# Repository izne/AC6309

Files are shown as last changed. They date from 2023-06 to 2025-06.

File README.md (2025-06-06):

# AC6309 Platform
A minimalistic industrial computer core, based on Motorola 6809 architecture.

## Purpose
Proof of concept custom 8-bit industrial computer with minimal device count implementation. Modular, low-power design, allowing easy expansion and customization per use case.

## Dedication
AC29 is dedicated to my beloved father.

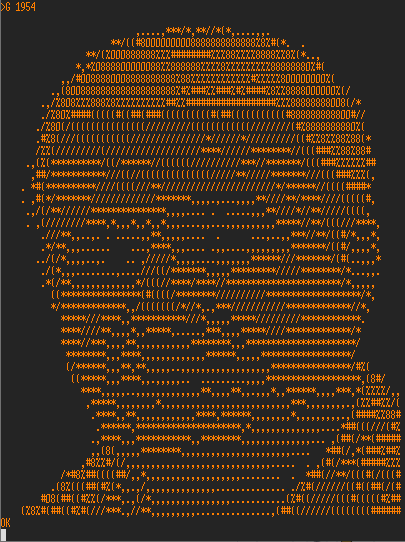
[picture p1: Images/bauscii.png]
BAUS


## AC29 projected configuration
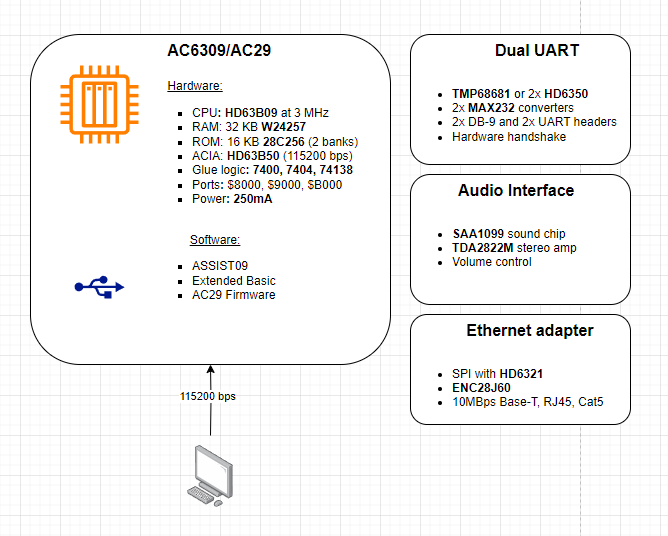
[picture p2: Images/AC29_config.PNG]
AC29 Config


## Prototype build 
* CPU: HD63B09 @ 1.8432MHz
* RAM: 32KB W24257A
* ROM: 8KB 28C256 (2x ROMs)
* UART: HD63B50 (1MBps) on FT23 USB Serial
* Address decoding: 74HCT00 & 74HCT138
* Expansion: 1x 40-pin header for expansion board with 3 slots mapped at $8000, $9000 and $B000
* Power over USB

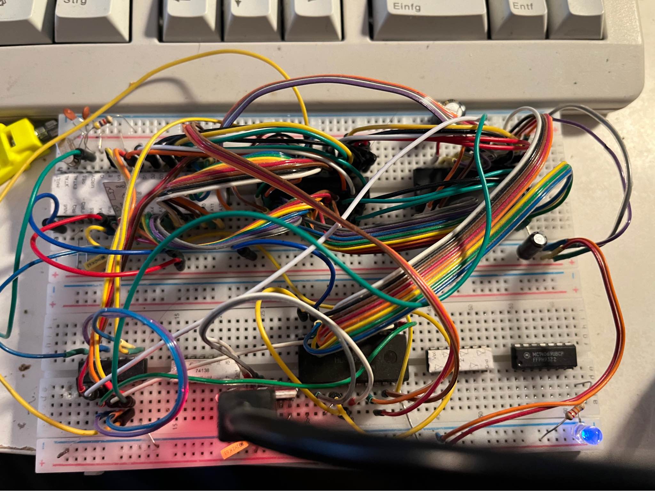
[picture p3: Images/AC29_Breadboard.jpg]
AC29 Breadboard


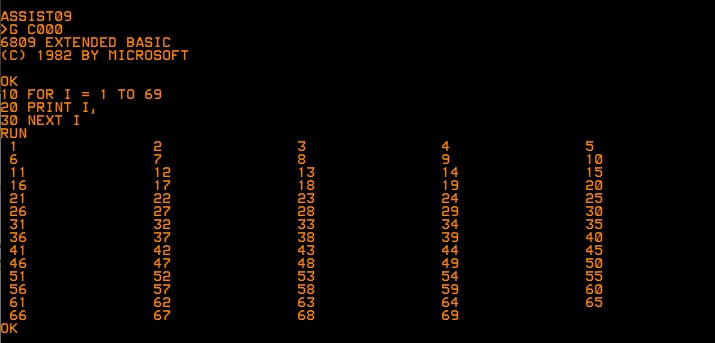
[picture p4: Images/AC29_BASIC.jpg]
AC29 BASIC


## Example physical layout
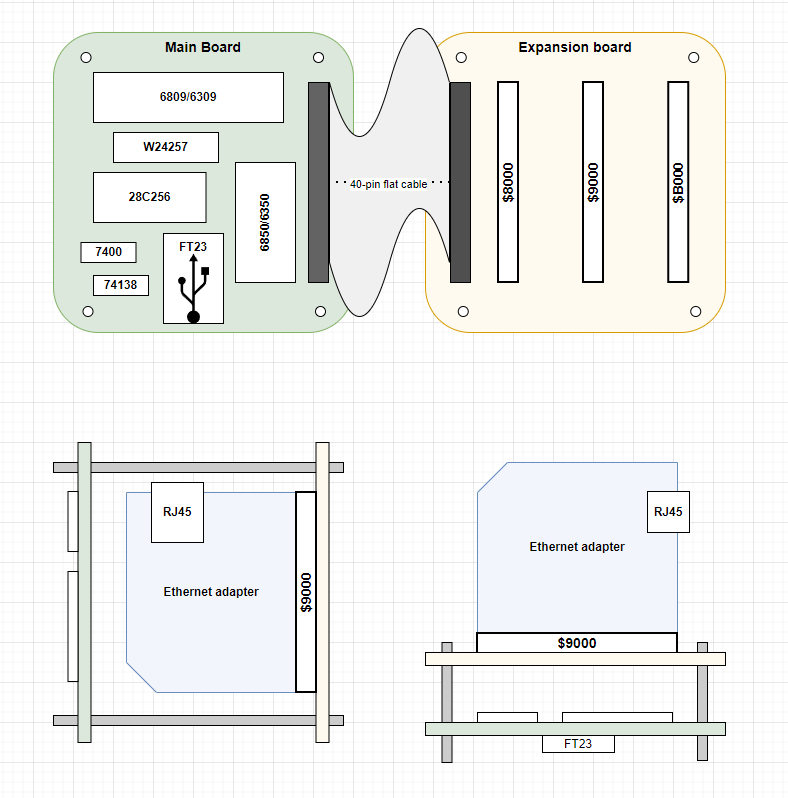
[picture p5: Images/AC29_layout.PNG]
AC29 Layout


## PCB Updates
Current state of PCB design:
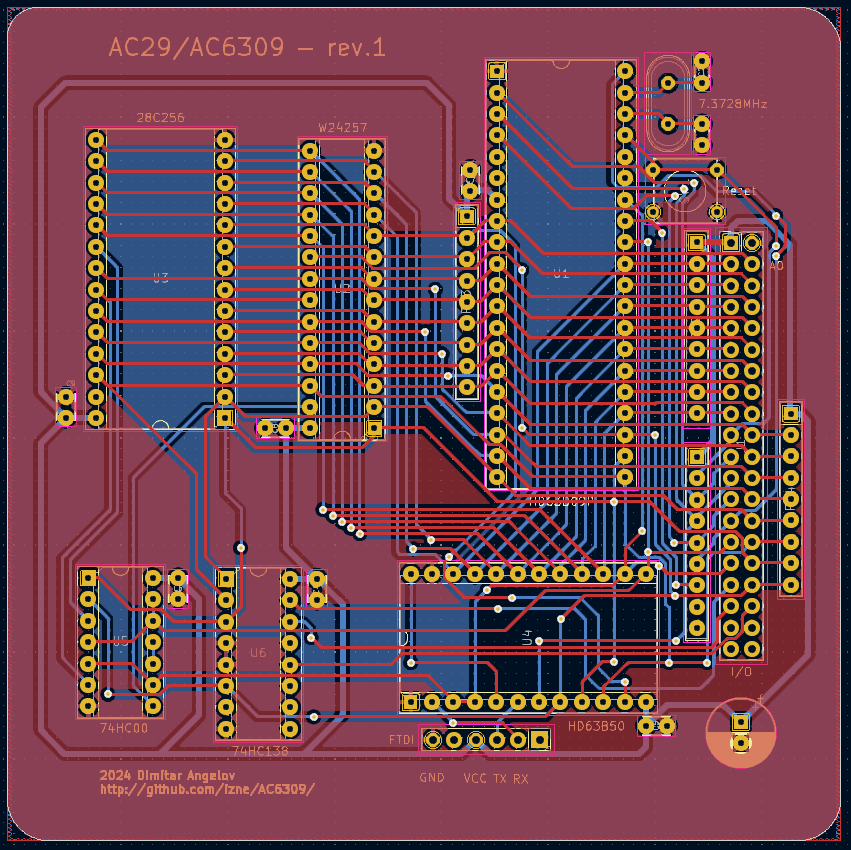
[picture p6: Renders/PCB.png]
AC29 PCB

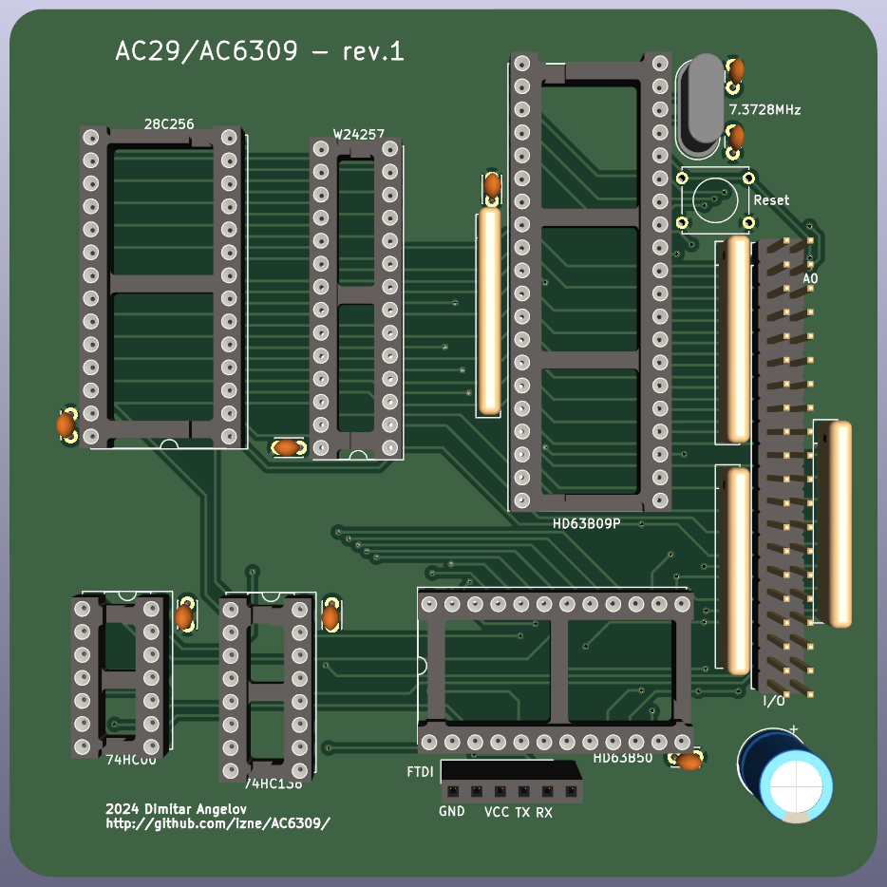
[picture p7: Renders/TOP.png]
AC29 TOP

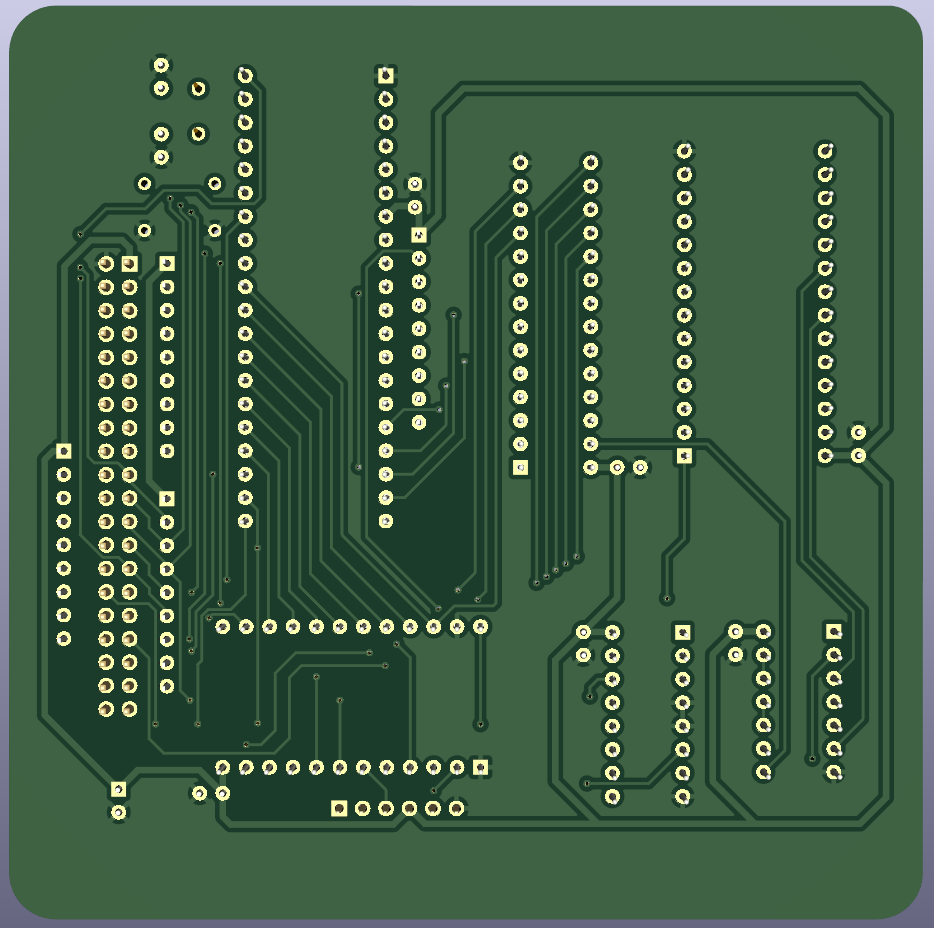
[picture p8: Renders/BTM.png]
AC29 BTM


## System memory map
|Address range|Device|Size|
|---|---|----|
|$0000-$7FFF|RAM|32KB|
|$8000-$8FFF|Extension port #1|4KB|
|$9000-$9FFF|Extension port #2|4KB|
|$A000-$AFFF|UART|4KB|
|$B000-$BFFF|Extension port #3|4KB|
|$C000-$FFFF|ROM|16KB|

The 32KB of RAM is allocated from the bottom of the address range $0000 to $7FFF.
The ROM is allocated at top 8KB of the address space starting $C000 to $DFFF.

The I/O mapping is allowing compatibility with existing BIOS images having ACIA on address 0xA000. 

## Writing the ROM image
Using the combination ROM image in Intel HEX format it needs first be turned into a binary image to be written to the EEPROM.
> objcopy -I ihex -O binary combined.hex combined.bin

Write the resulting .bin file using the specially created EEPROM programmer for AT28C-series EEPROMs. Or any other.
> promdude.exe -f combined.bin

As a note, burning the combined.bin (16K) onto 32K 28C256 has to be at the correct half. Optionally, a copy of combined.bin twice into the chip will do as well.

## ROM switching
As the firmware is 16K and 28C256 (32K) chips are nowadays more accesible, two firmware images could be stored in the full 32K capacity of the chip. A ROM switching key to be implemented on the board, to switch the higher or lower part of the chip to be "visible" (A14) at boot.

## Communication
The system communicates with a terminal via USB serial connection using the included ACIA device and its UART capability, coupled with an FTDI232 header. Terminal serial port settings: 115200 baud, 8n1, no hardware handshake yet.

## Software checklist
- [x] Run ASSIST09 and Extended BASIC
- [x] Write basic program (asm)
- [x] Cross-compile on host machine
- [x] Easy program transer via ASSIST09 Load (S19)
- [ ] Use of high level C code (CMOC)

## Hardware checklist
- [x] Breadboard prototype running
- [x] Revision 1 completion and PCB fabrication
- [ ] Extended addressing ("A" - four internal devices, "B" - four external devices)
- [ ] Expansion board with easy coupling
- [ ] 28C16-based address decoder
- [ ] Expansion card: Am9511 card (Am9511, 3MHz osc, 5to12Vbuck)
- [ ] Expansion card: Tape interface
- [ ] Expansion card: TMP68681 / 2x RS232 / 115200 bps (own osc)
- [ ] Expansion card: Ethernet adapter (ENC28J60)
- [ ] Expansion card: SAA1099 + TDA2822 audio interface
- [ ] Expansion card: VGA and PS/2 (Arduino)
- [ ] Expansion card: VGA and PS/2 (MC6845/HD6321)
- [ ] Expansion card: VGA (EF9367)
- [ ] Expansion card: Keyboard controller (XT, AT, PS/2, USB)

## Toolchain
* [ASM6809](https://www.6809.org.uk/asm6809/doc/asm6809.shtml)
* [A09](https://github.com/Arakula/A09)
* [AS09](https://gitlab.com/dfffffff/as09)
* [LWTOOLS-4.20](http://www.lwtools.ca/)
* [CMOC](http://perso.b2b2c.ca/~sarrazip/dev/cmoc.html)
* [MillFork](https://github.com/KarolS/millfork)

## Emulators
* [6809 online assembler](http://6809.uk/)
* [XRoar](https://www.6809.org.uk/xroar/online/)

- - - 
#### Prerequisites
The schematics and PCB design is made with [KiCad](http://kicad.org)

#### References and inspiration:
* [sbc689 by Jeff Tranter](https://github.com/jefftranter/6809)
* [6809 computer by Grant Searle](http://searle.x10host.com/6809/Simple6809.html)
* [HB6809 by Lindoran](https://github.com/lindoran/HB6809)
* [OMEN Kilo](https://github.com/omenmicro/kilo)
* [Chip Labels by Grant Searle](http://searle.x10host.com/labels/ChipLabels.pdf)

### Some great oldschool books:

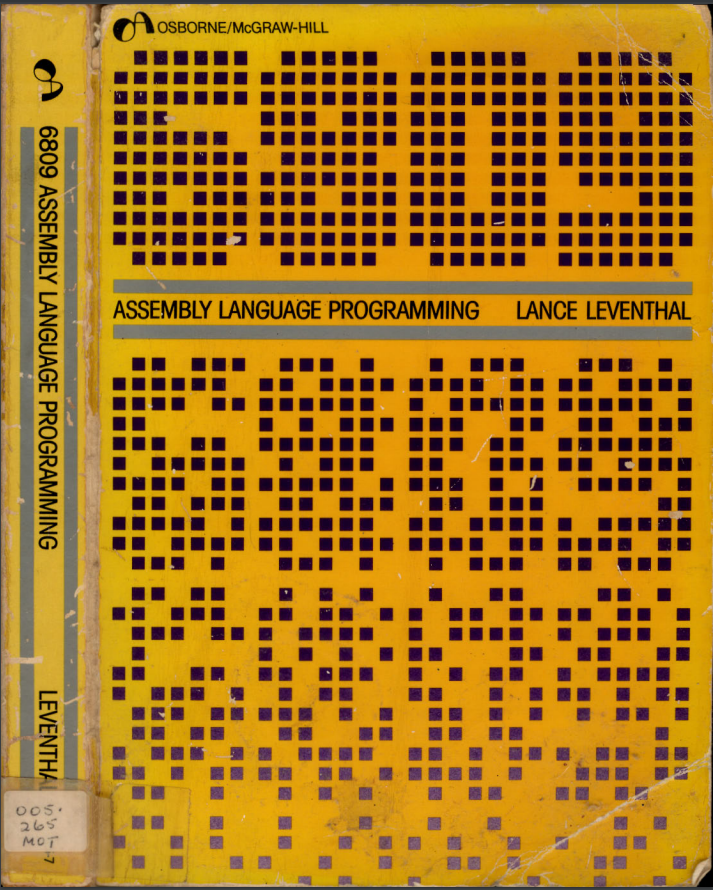
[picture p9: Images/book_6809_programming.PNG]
6809 Assembly Programming (https://colorcomputerarchive.com/repo/Documents/Books/6809%20Assembly%20Language%20Programming%20(Lance%20Leventhal).pdf)
* 

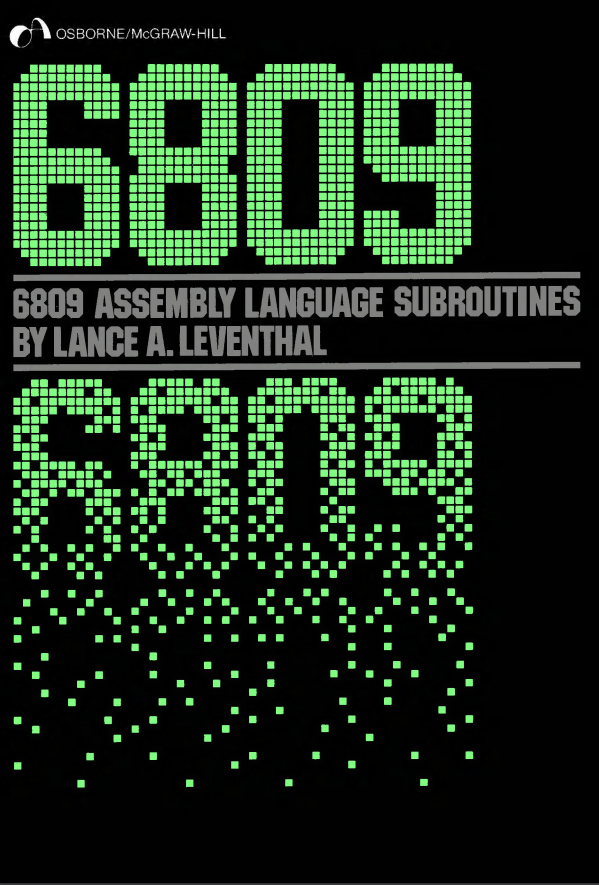
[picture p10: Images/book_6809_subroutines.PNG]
6809 Assembly Subroutines (https://colorcomputerarchive.com/repo/Documents/Books/6809%20Assembly%20Language%20Subroutines%20(Lance%20Leventhal).pdf)
* 

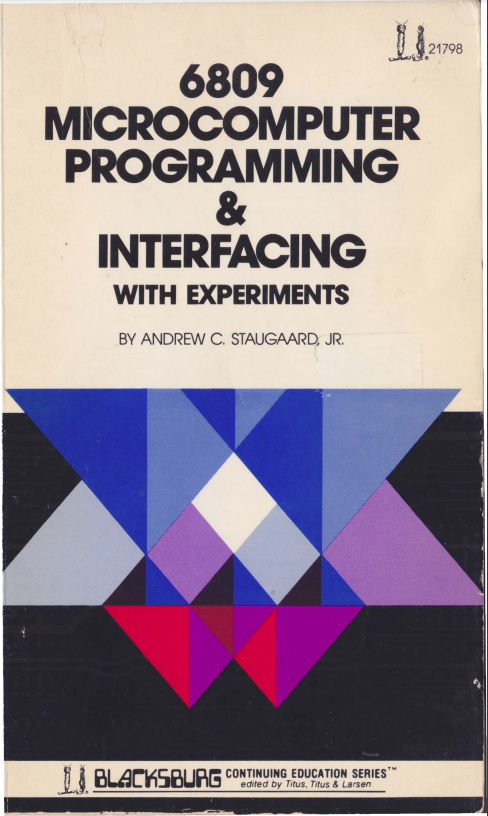
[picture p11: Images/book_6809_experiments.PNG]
6809 Microcomputer Programming and Interfacing with Experiments (https://colorcomputerarchive.com/repo/Documents/Books/6809%20Microcomputer%20Programming%20and%20Interfacing%20with%20Experiments%20(Andrew%20C.%20Staugaard%20Jr.).p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)
* 

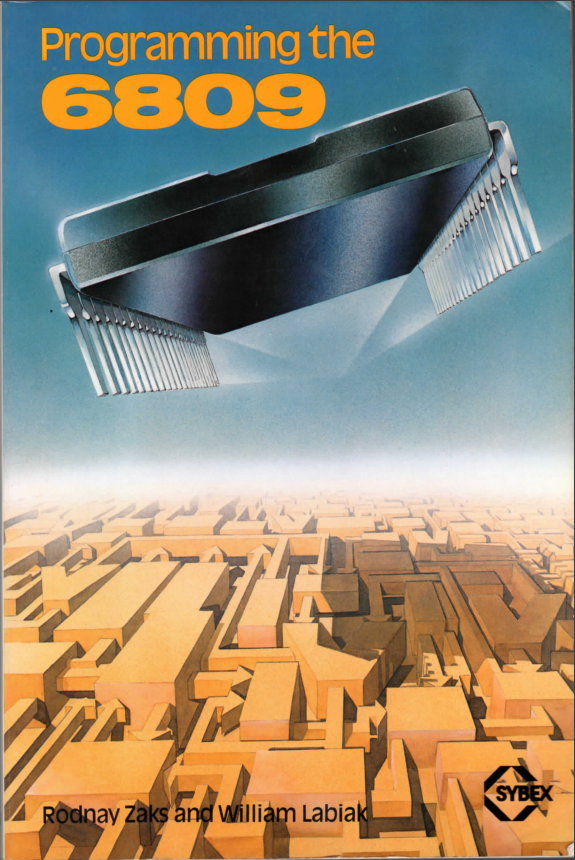
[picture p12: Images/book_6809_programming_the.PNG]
Programming the 6809 (https://colorcomputerarchive.com/repo/Documents/Books/Programming%20the%206809%20(Rodney%20Zaks%20and%20William%20Labiak).pdf)
* 

* [The 6309 Book](https://colorcomputerarchive.com/repo/Documents/Books/The%206309%20Book%20(Burke%20&%20Burke).pdf)

https://colorcomputerarchive.com/repo/Documents/Books/Programming%20the%206809%20(Rodney%20Zaks%20and%20William%20Labiak).pdf

https://www.chibiakumas.com/6809/

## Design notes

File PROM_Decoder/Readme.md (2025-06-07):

# AC6309 Address Decoder EEPROM Programming Script

This script generates a truth table and a binary file (`ac6309_decoder.bin`) for programming an AT28C64 EEPROM (8Kx8) to serve as an address decoder for the AC6309 single board computer. The EEPROM provides active-low chip select signals for various internal devices and expansion slots based on the upper address lines (A15–A8).

## Memory Map

- **0000–7FFF**: 32K RAM (handled by 7400 logic, not controlled by the EEPROM)
- **8000–9FFF**: Unmapped space (not decoded by the EEPROM)
- **A000–A0FF**: UART_CS (internal UART device)
- **A100–A1FF**: PIA_CS (internal PIA device)
- **A200–A2FF**: INT2_CS (internal interrupt 2 device)
- **A300–A3FF**: INT3_CS (internal interrupt 3 device)
- **B000–B0FF**: EXT1_CS (expansion slot 1)
- **B100–B1FF**: EXT2_CS (expansion slot 2)
- **B200–B2FF**: EXT3_CS (expansion slot 3)
- **B300–B3FF**: EXT4_CS (expansion slot 4)
- **C000–FFFF**: 16K ROM (handled by 7400 logic, not controlled by the EEPROM)

The EEPROM's 8K address space (0x0000–0x1FFF) is used to generate chip select outputs for the A000–B3FF range, with each 256-byte block (e.g., A000–A0FF) producing identical output patterns.

## EEPROM AT28C64 DIP28 Pin Mapping

### Inputs (A15–A8)
- A0 (pin 2): A8
- A1 (pin 3): A9
- A2 (pin 4): A10
- A3 (pin 5): A11
- A4 (pin 6): A12
- A5 (pin 7): A13
- A6 (pin 8): A14
- A7 (pin 9): A15
- A8–A12 (pins 10–14): Tied to ground (not used)

### Outputs (Active-Low Chip Selects)
- D7 (pin 23): /UART_CS
- D6 (pin 22): /PIA_CS
- D5 (pin 21): /INT2_CS
- D4 (pin 20): /INT3_CS
- D3 (pin 19): /EXT1_CS
- D2 (pin 1): /EXT2_CS
- D1 (pin 28): /EXT3_CS
- D0 (pin 27): /EXT4_CS

## Script Functionality

### Purpose
The script generates:
- A truth table displaying the first address of each 256-byte block where the EEPROM controls a device.
- A binary file (`ac6309_decoder.bin`) containing 8192 bytes (8K) of data to program the AT28C64 EEPROM.

### Logic
- The script iterates over the EEPROM's 8K address space (0x0000–0x1FFF), extracting A15–A8 bits.
- Chip select outputs are calculated using AND logic based on A15–A8 bit patterns for each 256-byte region (e.g., A000–A0FF for /UART_CS).
- The lower 8 bits (A7–A0) do not affect the EEPROM output, as the chip select remains constant within each 256-byte block.
- Outputs are inverted to active-low and stored in the binary file.

### Output
- **Truth Table**: Displays the address, device name, range, and active-low chip select states for the first address of each controlled region (A000, A100, etc.).
- **Binary File**: `ac6309_decoder.bin` contains 8192 bytes, with each byte representing the inverted chip select pattern for the corresponding 256-byte block in the 6809 address space.

### Notes
- Each 256-byte block (e.g., A000–A0FF) has identical EEPROM outputs, determined by the A15–A8 bits.
- Regions 0000–7FFF (RAM) and C000–FFFF (ROM) are handled by 7400 logic and marked as "not EEPROM-controlled" in the output.
- The unmapped space (8000–9FFF) is also noted but not actively decoded by the EEPROM.

## Usage
1. Run the script: `python script_name.py`
2. Check the console for the truth table output.
3. Use the generated `ac6309_decoder.bin` file to program an PROM of the decoder.

## Example Output
``` python
Address  Device       Range           | /UART_CS /PIA_CS  /INT2_CS /INT3_CS /EXT1_CS /EXT2_CS /EXT3_CS /EXT4_CS
---------------------------------------------------------------------------------------------------------------
$A000    UART         A000-A0FF       |        0        1        1        1        1        1        1        1
$A100    PIA          A100-A1FF       |        1        0        1        1        1        1        1        1
$A200    INT2         A200-A2FF       |        1        1        0        1        1        1        1        1
$A300    INT3         A300-A3FF       |        1        1        1        0        1        1        1        1
$B000    EXT1         B000-B0FF       |        1        1        1        1        0        1        1        1
$B100    EXT2         B100-B1FF       |        1        1        1        1        1        0        1        1
$B200    EXT3         B200-B2FF       |        1        1        1        1        1        1        0        1
$B300    EXT4         B300-B3FF       |        1        1        1        1        1        1        1        0
```

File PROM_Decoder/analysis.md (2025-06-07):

# AC6309 Decoder BIN File Byte-by-Byte Analysis Summary

This document provides a summary of the byte-by-byte analysis of the `ac6309_decoder.bin` file, a 8192-byte (8K) binary file generated for programming an AT28C64 EEPROM to serve as an address decoder for the AC6309 single board computer. The analysis verifies the contents against the script's logic, which maps EEPROM addresses (0x0000–0x1FFF) to 256-byte blocks in the 6809 address space, with inverted active-low chip select outputs.

## File Overview
- **Size**: 8192 bytes (0x2000)
- **Purpose**: Defines chip select signals (/UART_CS, /PIA_CS, /INT2_CS, /INT3_CS, /EXT1_CS, /EXT2_CS, /EXT3_CS, /EXT4_CS) for address ranges $A000–$B3FF.
- **Pattern**: Each byte corresponds to a 256-byte block, with identical values repeating every 256 bytes (0x100 indices) due to A7–A0 not affecting the output.

## Byte Mapping
The EEPROM address `i` (0x0000–0x1FFF) determines the upper address bits (A15–A8), and the byte at index `i` represents the inverted chip select pattern for the corresponding 256-byte block (e.g., $i << 8). The expected values are derived from the script's logic:
- **0xFF**: No chip select active (unmapped or 7400-controlled regions).
- **0x7F**: /UART_CS active ($A000–$A0FF).
- **0xBF**: /PIA_CS active ($A100–$A1FF).
- **0xDF**: /INT2_CS active ($A200–$A2FF).
- **0xEF**: /INT3_CS active ($A300–$A3FF).
- **0xF7**: /EXT1_CS active ($B000–$B0FF).
- **0xFB**: /EXT2_CS active ($B100–$B1FF).
- **0xFD**: /EXT3_CS active ($B200–$B2FF).
- **0xFE**: /EXT4_CS active ($B300–$B3FF).

## Detailed Analysis by 256-Byte Cycles
The file contains 32 cycles of 256 bytes (0x100). Below is a summary of the first cycle (indices 0–255) and the pattern's repetition:

### Cycle 0 (Indices 0x0000–0x00FF)
- **0x0000–0x009F (0–159)**: `0xFF` (unmapped, e.g., $0000–$9F00).
- **0x00A0 (160)**: `0x7F` (/UART_CS, $A000–$A0FF).
- **0x00A1 (161)**: `0xBF` (/PIA_CS, $A100–$A1FF).
- **0x00A2 (162)**: `0xDF` (/INT2_CS, $A200–$A2FF).
- **0x00A3 (163)**: `0xEF` (/INT3_CS, $A300–$A3FF).
- **0x00A4–0x00AF (164–175)**: `0xFF` (unmapped between $A3FF and $B000).
- **0x00B0 (176)**: `0xF7` (/EXT1_CS, $B000–$B0FF).
- **0x00B1 (177)**: `0xFB` (/EXT2_CS, $B100–$B1FF).
- **0x00B2 (178)**: `0xFD` (/EXT3_CS, $B200–$B2FF).
- **0x00B3 (179)**: `0xFE` (/EXT4_CS, $B300–$B3FF).
- **0x00B4–0x00FF (180–255)**: `0xFF` (unmapped beyond $B3FF).

### Subsequent Cycles (Indices 0x0100–0x1FFF)
- The pattern repeats every 256 bytes:
  - **0x0100–0x019F**: `0xFF`..., `0x7F`, `0xBF`, `0xDF`, `0xEF`, ..., `0xF7`, `0xFB`, `0xFD`, `0xFE`, `0xFF`...
  - **0x0200–0x029F**: Same pattern shifted.
  - Continues up to **0x1F00–0x1FFF**, maintaining consistency.
- Total cycles: 32 (0x0000–0x1F00), with the last cycle (0x1C00–0x1FFF) following the same structure.

## Verification Results
- **Match**: The pasted data (`FF...7F BF DF EF...F7 FB FD FE...FF`) aligns with the expected values at indices 160–163 and 176–179 in each 256-byte cycle.
- **Consistency**: The `0xFF` padding for unmapped regions and the repetition every 256 bytes match the script's design.
- **Integrity**: The 8192-byte length and uniform pattern confirm the file’s correctness.

## Conclusion
The `ac6309_decoder.bin` file accurately reflects the AC6309 address decoder logic, with:
- Active-low chip selects correctly assigned to $A000–$B3FF ranges.
- Unmapped or 7400-controlled regions (e.g., $0000–$9FFF, $B400–$FFFF) set to `0xFF`.
- A total of 8192 bytes, ready for AT28C64 programming.

This file can be confidently used to program the EEPROM. For further validation, use a hex editor to confirm the pattern across all cycles.

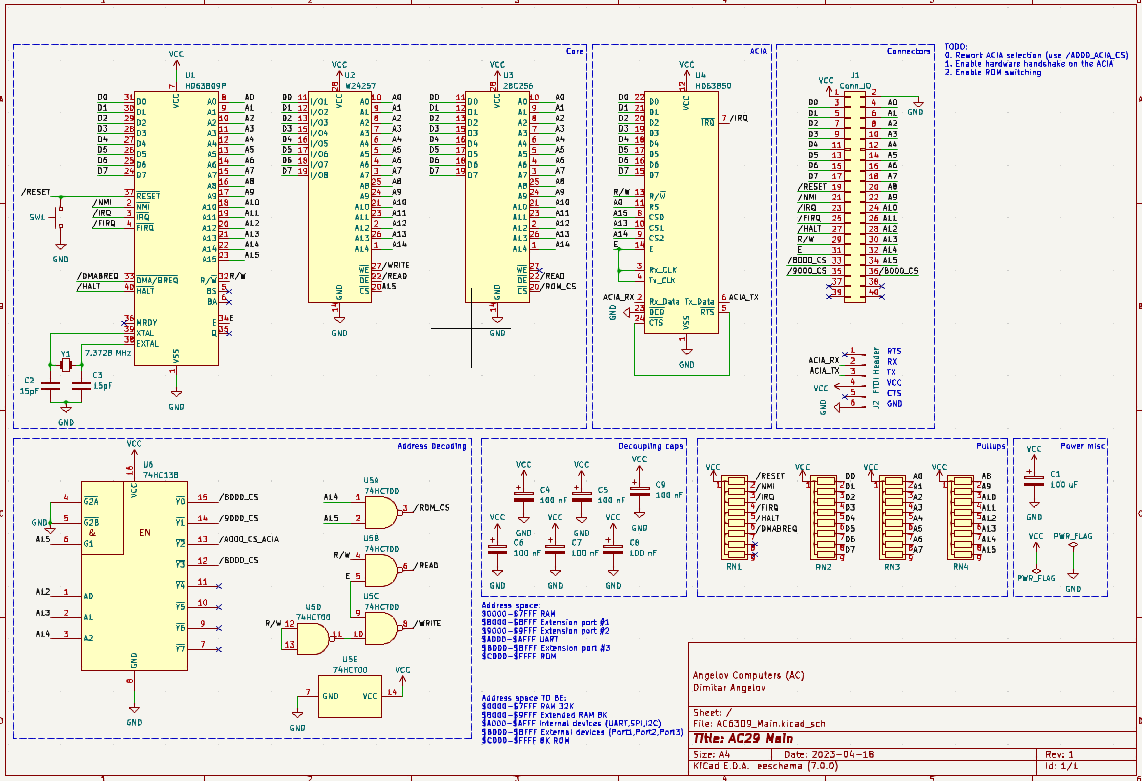
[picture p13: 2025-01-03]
Renders/SCH.png

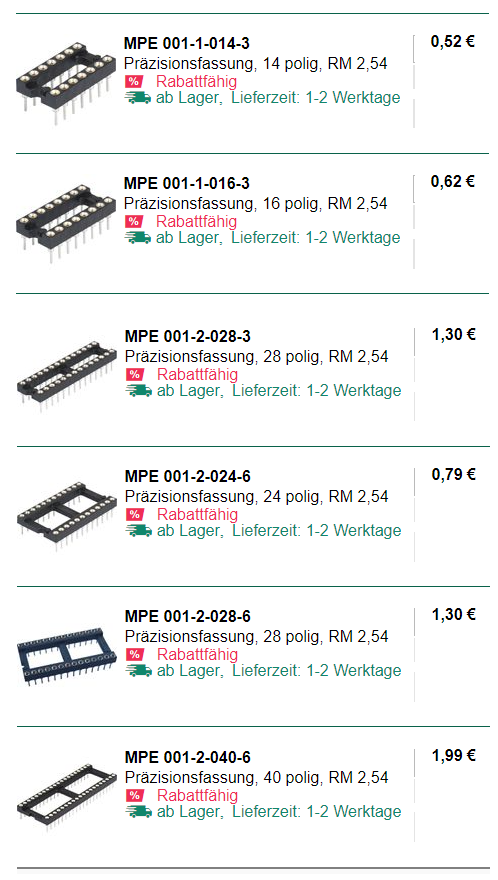
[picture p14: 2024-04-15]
Images/Sockets_Reichelt.png

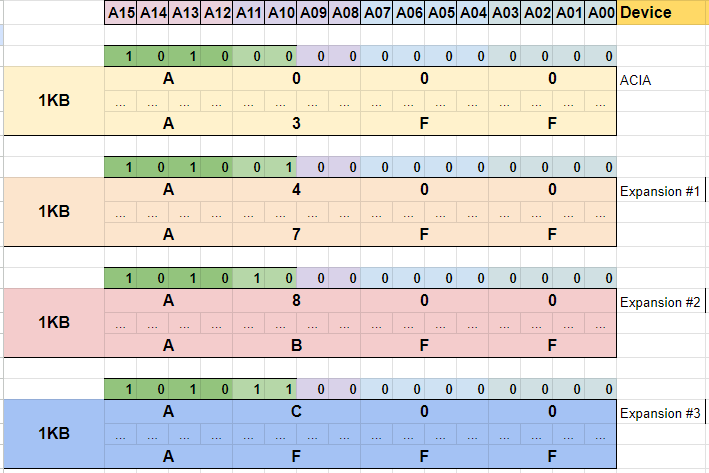
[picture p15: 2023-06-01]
Renders/AC6309_IOmap.PNG

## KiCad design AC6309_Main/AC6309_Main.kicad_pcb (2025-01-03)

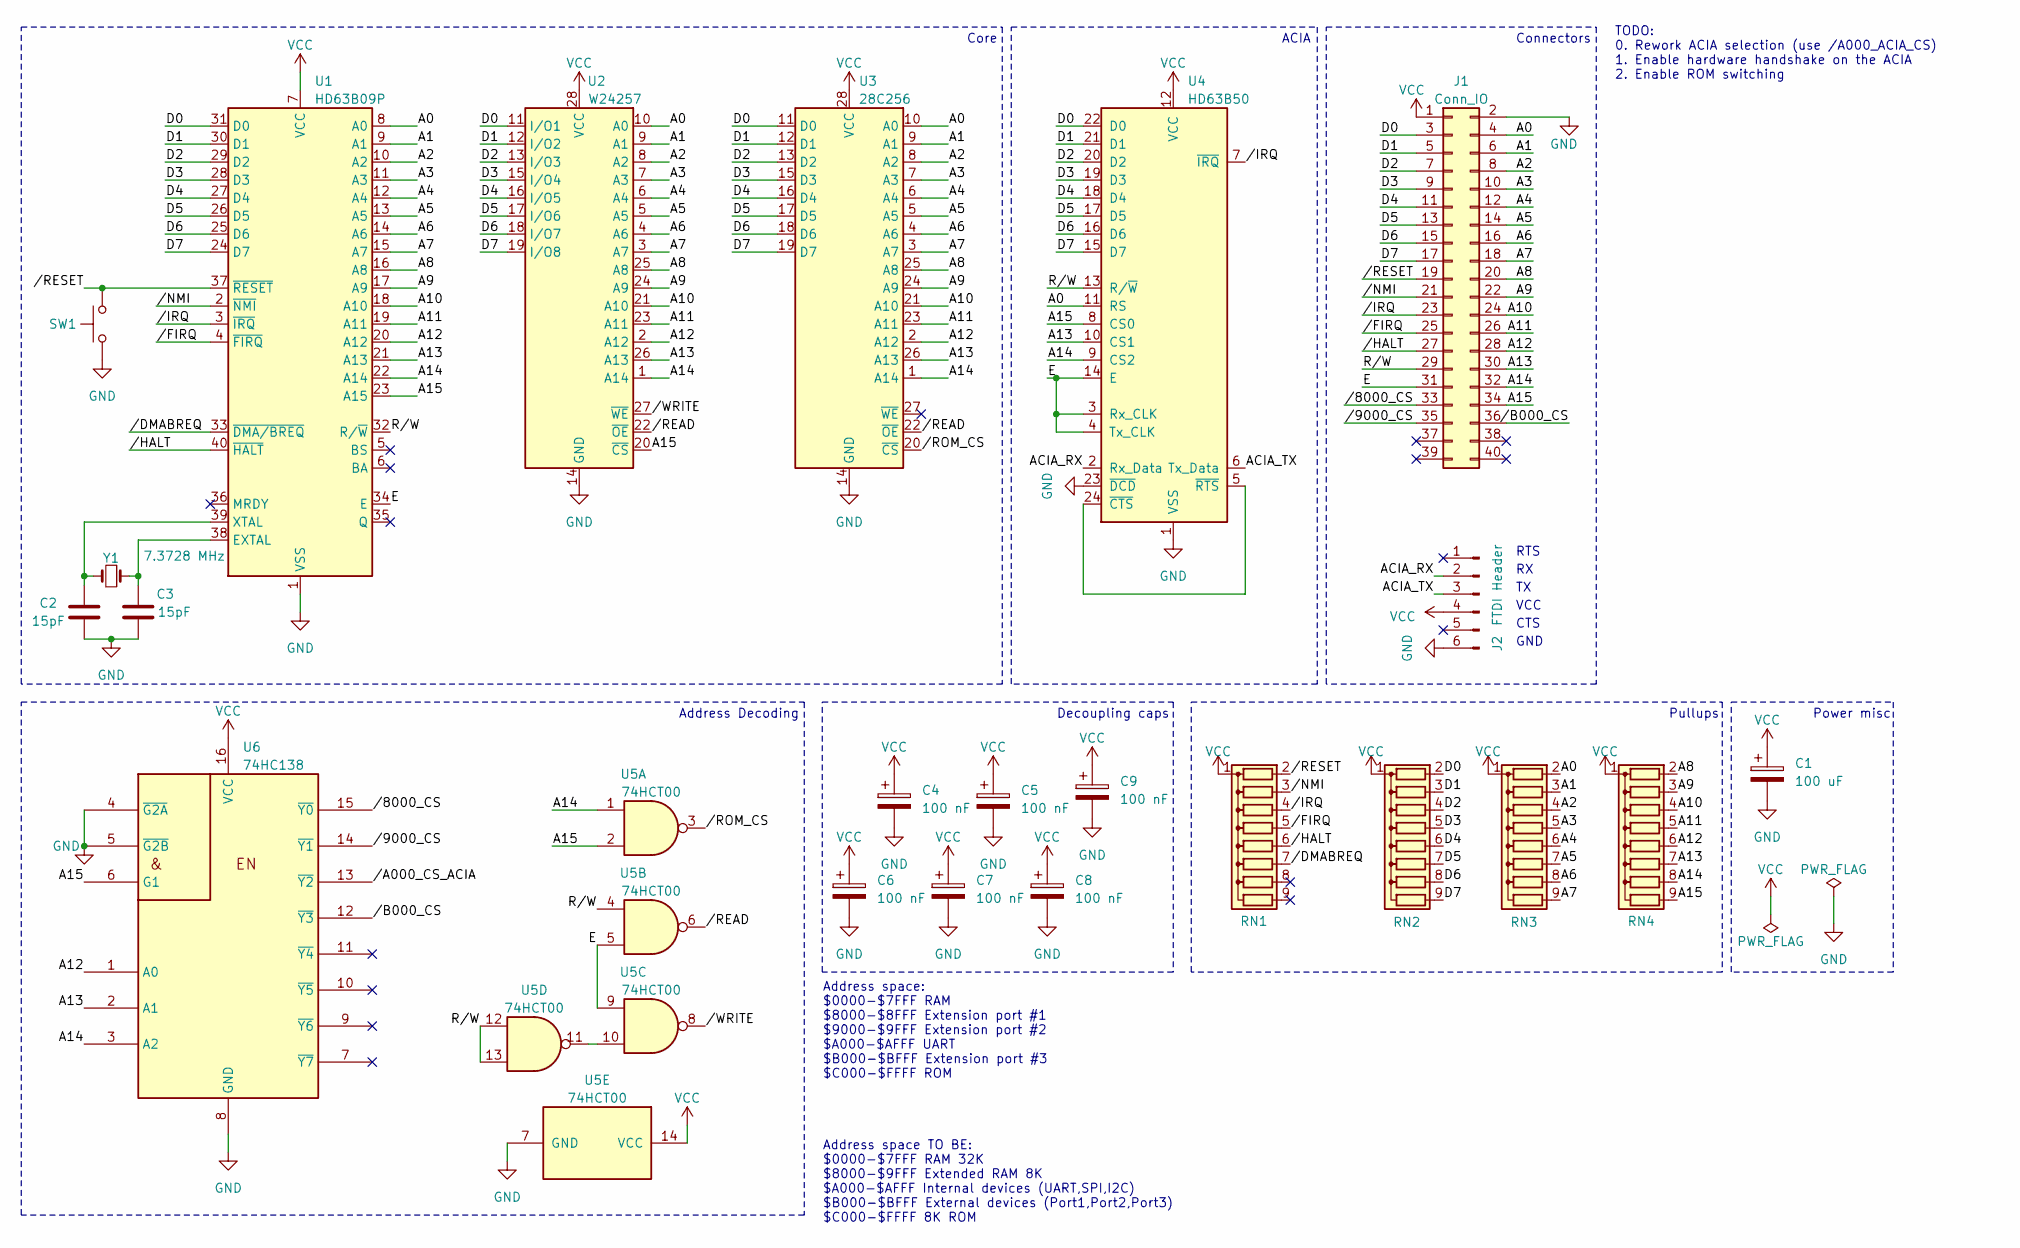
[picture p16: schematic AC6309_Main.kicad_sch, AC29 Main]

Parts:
C1: 100 uF; CP_Radial_D8.0mm_P2.50mm
C2, C3: 15pF; C_Disc_D3.0mm_W1.6mm_P2.50mm
C4, C5, C6, C7, C8, C9: 100 nF; C_Disc_D3.0mm_W2.0mm_P2.50mm
J1: Conn_IO; PinHeader_2x20_P2.54mm_Vertical
J2: FTDI Header; PinSocket_1x06_P2.54mm_Vertical
RN1, RN2, RN3, RN4: R_Network08; R_Array_SIP9
SW1: Reset; SW_Tactile_Straight_KSL0Axx1LFTR
U1: HD63B09P; DIP-40_W15.24mm_Socket
U2: W24257; DIP-28_W7.62mm_Socket
U3: 28C256; DIP-28_W15.24mm_Socket
U4: HD63B50; DIP-24_W15.24mm_Socket
U5: 74HCT00; DIP-14_W7.62mm_Socket
U6: 74HC138; DIP-16_W7.62mm_Socket
Y1: 7.3728 MHz; Crystal_HC49-4H_Vertical

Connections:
/A0: J1.4, RN3.2 (R1), U1.8 (A0), U2.10 (A0), U3.10 (A0), U4.11 (RS)
/A1: J1.6, RN3.3 (R2), U1.9 (A1), U2.9 (A1), U3.9 (A1)
/A2: J1.8, RN3.4 (R3), U1.10 (A2), U2.8 (A2), U3.8 (A2)
/A3: J1.10, RN3.5 (R4), U1.11 (A3), U2.7 (A3), U3.7 (A3)
/A4: J1.12, RN3.6 (R5), U1.12 (A4), U2.6 (A4), U3.6 (A4)
/A5: J1.14, RN3.7 (R6), U1.13 (A5), U2.5 (A5), U3.5 (A5)
/A6: J1.16, RN3.8 (R7), U1.14 (A6), U2.4 (A6), U3.4 (A6)
/A7: J1.18, RN3.9 (R8), U1.15 (A7), U2.3 (A7), U3.3 (A7)
/A8: J1.20, RN4.2 (R1), U1.16 (A8), U2.25 (A8), U3.25 (A8)
/A9: J1.22, RN4.3 (R2), U1.17 (A9), U2.24 (A9), U3.24 (A9)
/A10: J1.24, RN4.4 (R3), U1.18 (A10), U2.21 (A10), U3.21 (A10)
/A11: J1.26, RN4.5 (R4), U1.19 (A11), U2.23 (A11), U3.23 (A11)
/A12: J1.28, RN4.6 (R5), U1.20 (A12), U2.2 (A12), U3.2 (A12), U6.1 (A0)
/A13: J1.30, RN4.7 (R6), U1.21 (A13), U2.26 (A13), U3.26 (A13), U4.10 (CS1), U6.2 (A1)
/A14: J1.32, RN4.8 (R7), U1.22 (A14), U2.1 (A14), U3.1 (A14), U4.9 (CS2), U5.1, U6.3 (A2)
/A15: J1.34, RN4.9 (R8), U1.23 (A15), U2.20 (~CS), U4.8 (CS0), U5.2, U6.6 (G1)
/ACIA_RX: J2.2, U4.2 (Rx_Data)
/ACIA_TX: J2.3, U4.6 (Tx_Data)
/D0: J1.3, RN2.2 (R1), U1.31 (D0), U2.11 (I/O1), U3.11 (D0), U4.22 (D0)
/D1: J1.5, RN2.3 (R2), U1.30 (D1), U2.12 (I/O2), U3.12 (D1), U4.21 (D1)
/D2: J1.7, RN2.4 (R3), U1.29 (D2), U2.13 (I/O3), U3.13 (D2), U4.20 (D2)
/D3: J1.9, RN2.5 (R4), U1.28 (D3), U2.15 (I/O4), U3.15 (D3), U4.19 (D3)
/D4: J1.11, RN2.6 (R5), U1.27 (D4), U2.16 (I/O5), U3.16 (D4), U4.18 (D4)
/D5: J1.13, RN2.7 (R6), U1.26 (D5), U2.17 (I/O6), U3.17 (D5), U4.17 (D5)
/D6: J1.15, RN2.8 (R7), U1.25 (D6), U2.18 (I/O7), U3.18 (D6), U4.16 (D6)
/D7: J1.17, RN2.9 (R8), U1.24 (D7), U2.19 (I/O8), U3.19 (D7), U4.15 (D7)
/E: J1.31, U1.34 (E), U4.3 (Rx_CLK), U4.4 (Tx_CLK), U4.14 (E), U5.5, U5.9
/R/W: J1.29, U1.32 (R/~W), U4.13 (R/~W), U5.4, U5.12, U5.13
//8000_CS: J1.33, U6.15 (~Y0)
//9000_CS: J1.35, U6.14 (~Y1)
//A000_CS_ACIA: U6.13 (~Y2)
//B000_CS: J1.36, U6.12 (~Y3)
//DMABREQ: RN1.7 (R6), U1.33 (~DMA/BREQ)
//FIRQ: J1.25, RN1.5 (R4), U1.4 (~FIRQ)
//HALT: J1.27, RN1.6 (R5), U1.40 (~HALT)
//IRQ: J1.23, RN1.4 (R3), U1.3 (~IRQ), U4.7 (~IRQ)
//NMI: J1.21, RN1.3 (R2), U1.2 (~NMI)
//READ: U2.22 (~OE), U3.22 (~OE), U5.6
//RESET: J1.19, RN1.2 (R1), SW1.2, U1.37 (~RESET)
//ROM_CS: U3.20 (~CS), U5.3
//WRITE: U2.27 (~WE), U5.8
GND: C1.2, C2.2, C3.2, C4.2, C5.2, C6.2, C7.2, C8.2, C9.2, J1.2, J2.6, SW1.1, U1.1 (VSS), U2.14 (GND), U3.14 (GND), U4.1 (VSS), U4.23 (~DCD), U5.7 (GND), U6.4 (~G2A), U6.5 (~G2B), U6.8 (GND)
unnamed: C3.1, U1.38 (EXTAL), Y1.1
unnamed: C2.1, U1.39 (XTAL), Y1.2
unnamed: U4.5 (~RTS), U4.24 (~CTS)
unnamed: U5.10, U5.11
VCC: C1.1, C4.1, C5.1, C6.1, C7.1, C8.1, C9.1, J1.1, J2.4, RN1.1 (common), RN2.1 (common), RN3.1 (common), RN4.1 (common), U1.7 (VCC), U2.28 (VCC), U3.28 (VCC), U4.12 (VCC), U5.14 (VCC), U6.16 (VCC)

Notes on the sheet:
Pullups
CTS
Power misc
Connectors
Address Decoding
Address space: $0000-$7FFF RAM $8000-$8FFF Extension port #1 $9000-$9FFF Extension port #2 $A000-$AFFF UART $B000-$BFFF Extension port #3 $C000-$FFFF ROM
TODO: 0. Rework ACIA selection (use /A000_ACIA_CS) 1. Enable hardware handshake on the ACIA 2. Enable ROM switching
GND
RTS
Core
Address space TO BE: $0000-$7FFF RAM 32K $8000-$9FFF Extended RAM 8K $A000-$AFFF Internal devices (UART,SPI,I2C) $B000-$BFFF External devices (Port1,Port2,Port3) $C000-$FFFF 8K ROM
Decoupling caps
VCC
ACIA

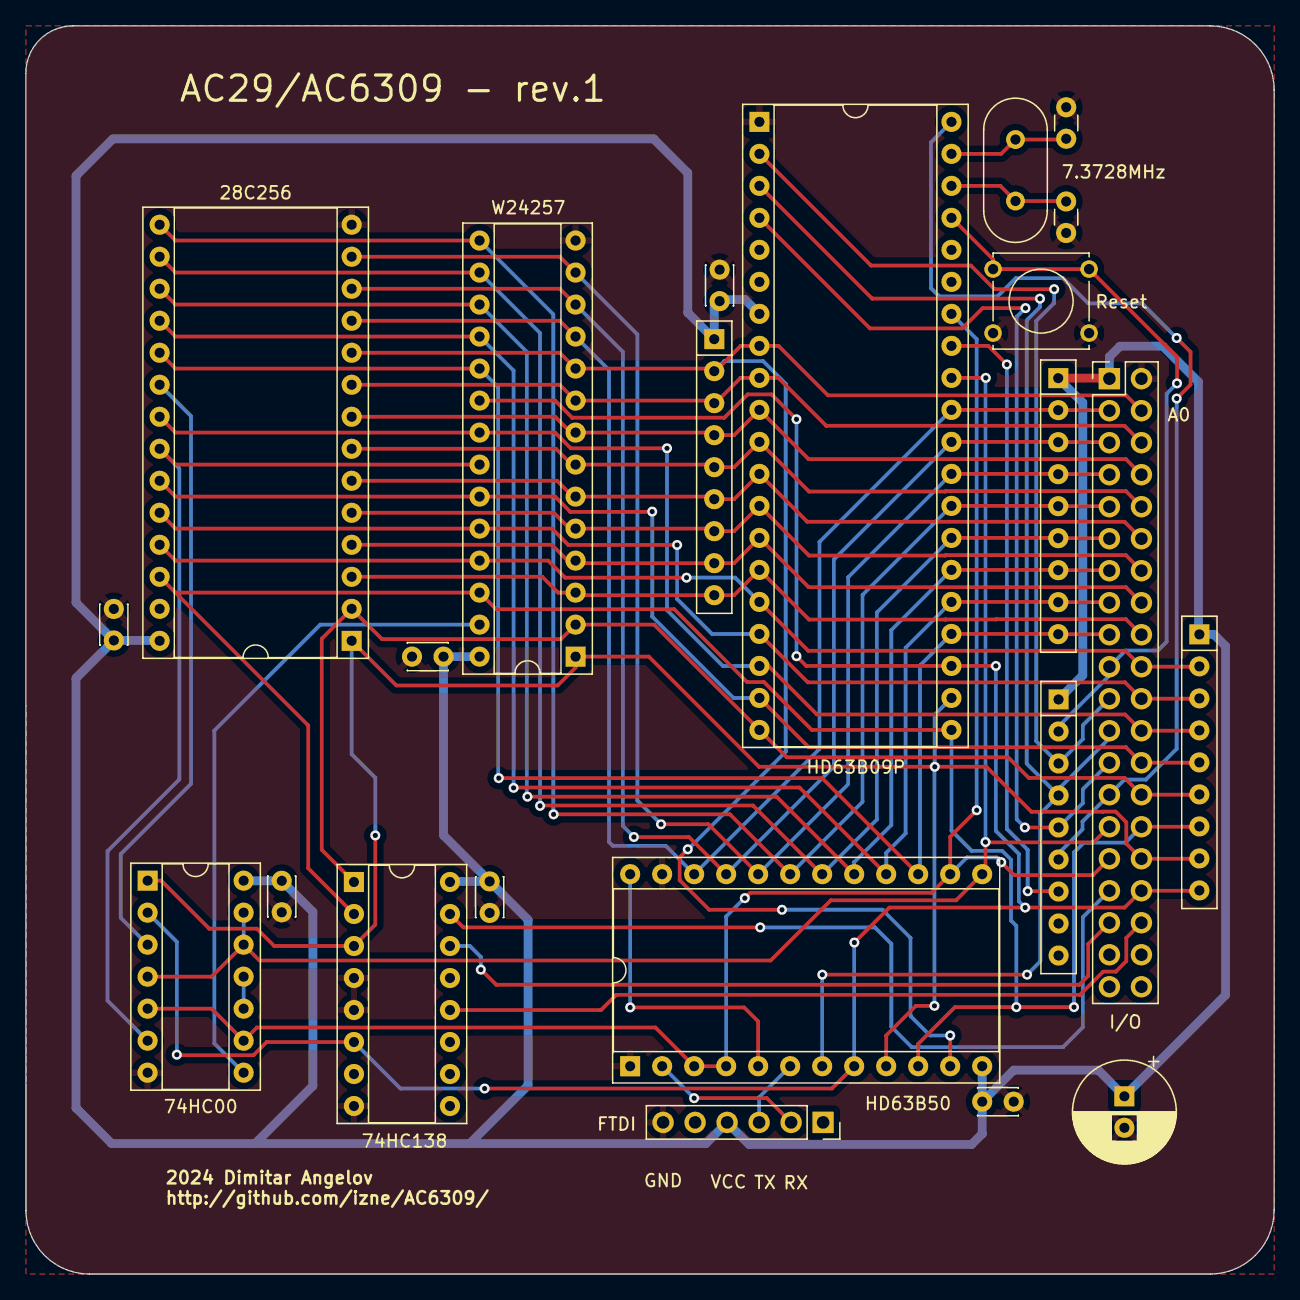
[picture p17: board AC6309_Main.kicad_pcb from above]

Board: 2 copper layers, 99.1 x 99.1 mm, 23 parts (0 on the bottom side), 46 nets.

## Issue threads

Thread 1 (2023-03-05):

Address decoder sufficiency

izne, 2023-03-05:
Using a single 74HC00 would be insufficient to make a decoder with the address mapping of all desired devices.
Instead, a 74HCT138 is to be used as it provides 8 outputs that could be used as a chip-select signal for more devices.

1. Connect A15, A14, and A13 of the HD6309 to the A0, A1, and A2 inputs of the 74HC138, respectively.
2. Connect the three enable inputs (G1, G2A, and G2B) of the 74HC138 as follows:
- G1 to VCC (logic high)
- G2A and G2B to ground (logic low)
3. Connect the eight outputs (Y0-Y7) of the 74HC138 to the CS (chip select) inputs of the RAM, ROM, and UART chips as follows:
- Y0 to the CS input of the first RAM chip
- Y1 to the CS input of the second RAM chip (for future expansion)
- Y2 to the CS input of the ROM chip
- Y3 to the CS input of the UART chip
- Y4-Y7 can be used as extension port CS pins or for other purposes.
4. Connect the outputs of the extension port devices to the appropriate pins on the HD6309, and use the corresponding 74HC138 output as the CS signal for each device.

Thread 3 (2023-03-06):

Connect TMP68681

izne, 2023-03-06:
Using the double-channel UART requires the following:
* Crystal oscillator: 1.8432 MHz for the baud rate generator
* Filtering caps
* additional circuitry

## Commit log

2023-03-05 Steigero init
    [AC6309_Main.kicad_pcb, AC6309_Main.kicad_sch]
2023-03-06 Adding 74HC138 to the address decoder
    [AC6309_Main.dsn, AC6309_Main.kicad_pcb, AC6309_Main.kicad_sch]
2023-03-09 Added resistor networks. Updated PCB layout. Added temporary freeroute traces.
    [AC6309_Main.dsn, AC6309_Main.kicad_pcb, AC6309_Main.kicad_sch]
2023-03-23 Replaced UART. Updates on Readme .
    [AC6309_Main.dsn, AC6309_Main.kicad_pcb, AC6309_Main.kicad_sch]
2023-06-01 Schematics revision 1, Digital file, etc.
    [AC6309_Main.dsn, AC6309_Main.kicad_pcb, AC6309_Main.kicad_sch]
2023-12-05 KiCad sync
    [AC6309_Main.kicad_sch]
2024-04-15 SCH and PCB updats. DRC issues fixed.
    [AC6309_Main.dsn, AC6309_Main.kicad_pcb, AC6309_Main.kicad_sch]
2025-01-03 Updates from 2024. Rev1 going in production.
    [AC6309_Main.dsn, AC6309_Main.kicad_pcb, AC6309_Main.kicad_sch]
